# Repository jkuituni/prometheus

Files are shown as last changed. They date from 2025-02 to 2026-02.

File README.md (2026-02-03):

# Prometheus

Prometheus is a WDC 65816 based SingleBoardComputer aimed to be a fully usable self-containing computer platform.

System specification:

* CPU: WDC 65816 at 8MHz
* ROM: 8kB Firmware boot EPROM
* RAM: Up to 16MB of RAM via 4x 30pin SIMMs
* Video: Custom graphics chip "GRACE"
* Audio: Ensoniq EN5503 DOC
* I/O: 
  - RS232 serial port
  - Centronics port
  - 2x Atari "standard" joystick ports
  - ps/2 keyboard port
  - IDE massstorage interface
  - Standard floppydrive interface
* Other: 
  - DS1501 Realtime clock
  - 2x 16bit expansion slot connectors
  - 8bit expansion header

The graphics is implemented with a custom video controller called "[GRaCE](https://github.com/jkuituni/GRaCE)" using an additional FPGA board that connects via the two 40pin connectors. 

System controller is a CPLD that ties in the system, It generates the chip selects, various control signals and contains a DRAM controller.

More accurate specifications regarding the memory layout, graphics capabilities and generic system description will be 
added as they become available.

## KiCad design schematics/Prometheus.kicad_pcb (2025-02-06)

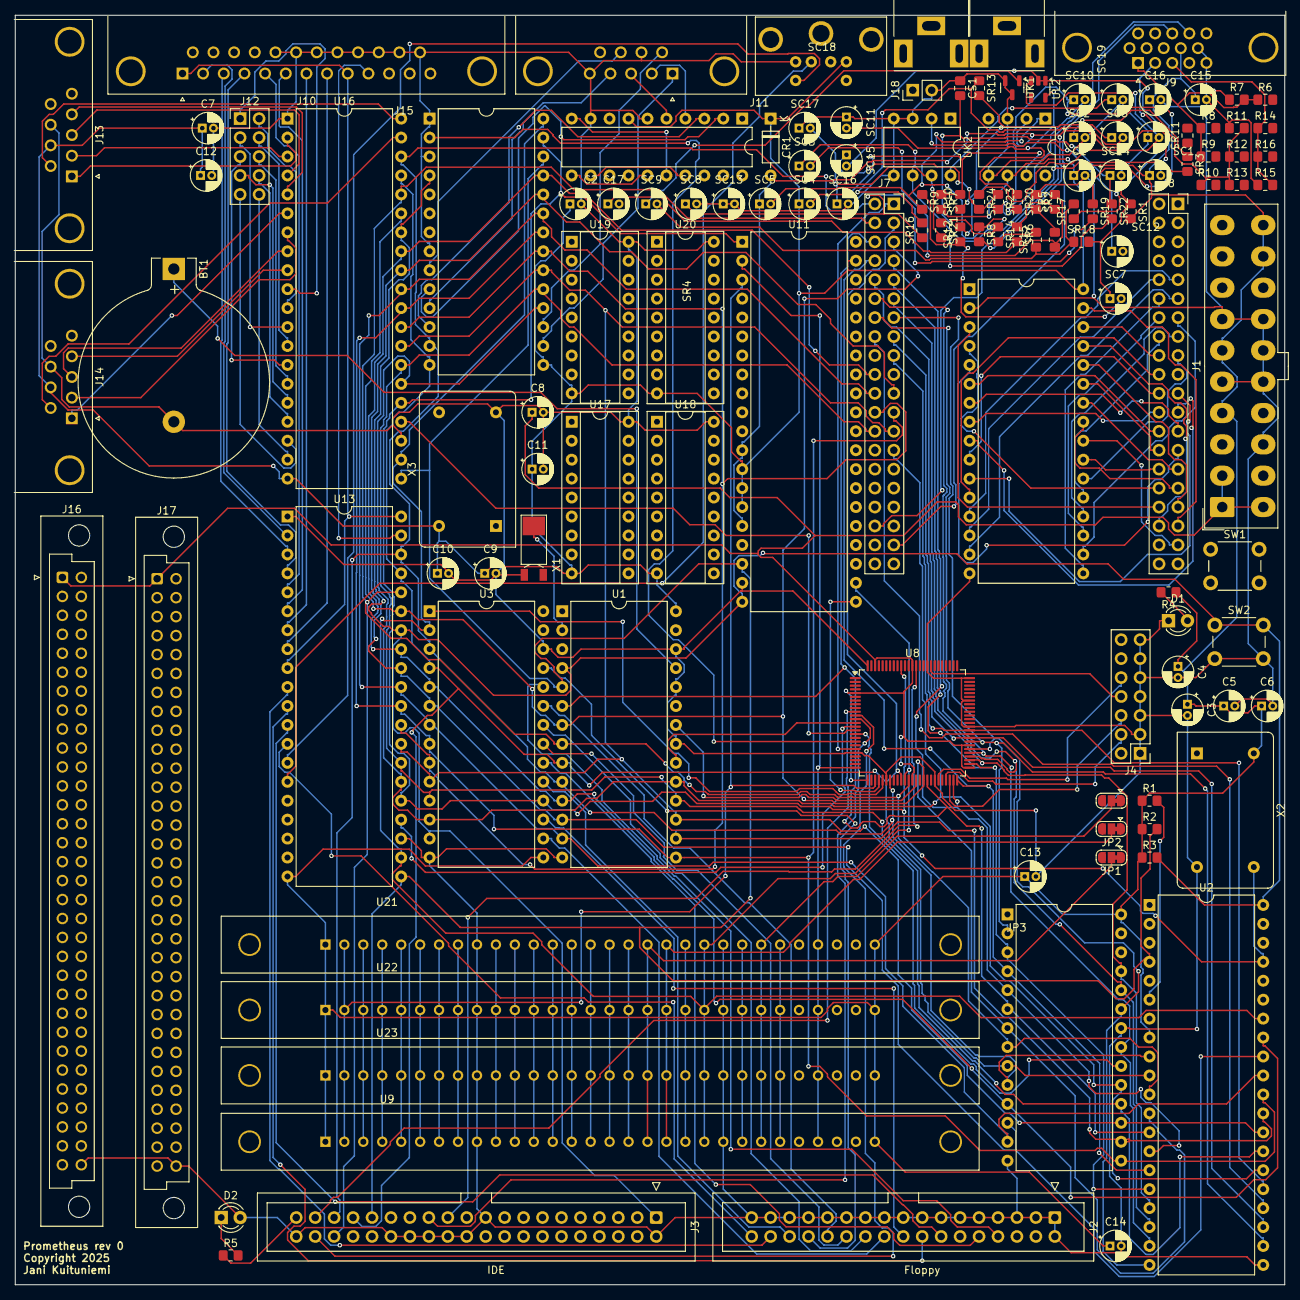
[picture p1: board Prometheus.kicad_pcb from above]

Board: 2 copper layers, 170.2 x 170.2 mm, 130 parts (0 on the bottom side), 191 nets.

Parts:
BT1: Battery; BatteryHolder_Keystone_104_1x23mm
C1, C2, C3, C4, C5, C6, C7, C8, C9, C10, C11: 0.1uF; CP_Radial_D4.0mm_P1.50mm
C12, C13, C14, C15, C16: C; CP_Radial_D4.0mm_P1.50mm
C17: 0.1u; CP_Radial_D4.0mm_P1.50mm
CR1: 1N914; D_DO-35_SOD27_P7.62mm_Horizontal
CS1: .1u; R_0805_2012Metric_Pad1.20x1.40mm_HandSolder
D1: Power LED; LED_D3.0mm
D2: IDE LED; LED_D3.0mm
J1: ATX Power Conn; Molex_Mini-Fit_Jr_5566-20A_2x10_P4.20mm_Vertical
J2: FDC Connector; IDC-Header_2x17_P2.54mm_Vertical
J3: IDE Connector; IDC-Header_2x20_P2.54mm_Vertical
J4: JTAG; PinHeader_2x07_P2.54mm_Vertical
J5: Left Audio; RCA
J6: Right Audio; RCA
J7: GRACE board interface 1; PinSocket_2x20_P2.54mm_Vertical
J8: GRACE board interface 2; PinSocket_2x20_P2.54mm_Vertical
J9: 15kHz Video Out; DSUB-15-HD_Female_Horizontal_P2.29x1.98mm_EdgePinOffset3.03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
J10: Centronics; DSUB-25_Female_Horizontal_P2.77x2.84mm_EdgePinOffset4.94mm_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
J11: ps/2 keyb; MINI-DIN-6-FULL-SHIELD
J12: Expansion; PinHeader_2x05_P2.54mm_Vertical
J13: Joy1; DSUB-9_Female_Horizontal_P2.77x2.84mm_EdgePinOffset4.94mm_H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
J14: Joy2; DSUB-9_Female_Horizontal_P2.77x2.84mm_EdgePinOffset4.94mm_H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
J15: rs232; DSUB-9_Male_Horizontal_P2.77x2.84mm_EdgePinOffset4.94mm_Hou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
J16, J17: DIN41612_02x32_AB; DIN41612_B_2x32_Female_Vertical_THT
J18: SPEAKER; PinHeader_1x02_P2.54mm_Vertical
JP1, JP2, JP3: Jumper_2_Open; SolderJumper-3_P1.3mm_Bridged12_RoundedPad1.0x1.5mm
R1, R2, R3, R5: R330; R_0805_2012Metric_Pad1.20x1.40mm_HandSolder
R4, R14: R470; R_0805_2012Metric_Pad1.20x1.40mm_HandSolder
R6, R10: R1100; R_0805_2012Metric_Pad1.20x1.40mm_HandSolder
R7, R11, R15: R150; R_0805_2012Metric_Pad1.20x1.40mm_HandSolder
R8, R12: R560; R_0805_2012Metric_Pad1.20x1.40mm_HandSolder
R9, R13: R270; R_0805_2012Metric_Pad1.20x1.40mm_HandSolder
R16: R240; R_0805_2012Metric_Pad1.20x1.40mm_HandSolder
SC1, SC4, SC5, SC6, SC7: 10p; CP_Radial_D4.0mm_P1.50mm
SC2, SC12, SC17: .1u; CP_Radial_D4.0mm_P1.50mm
SC3, SC9, SC16, SC19: 22u; CP_Radial_D4.0mm_P1.50mm
SC8: 1.5n; CP_Radial_D4.0mm_P1.50mm
SC10, SC15: 3.9n; CP_Radial_D4.0mm_P1.50mm
SC11: 220p; CP_Radial_D4.0mm_P1.50mm
SC13: 1.8n; CP_Radial_D4.0mm_P1.50mm
SC14: 470u/16v; CP_Radial_D4.0mm_P1.50mm
SC18: 560p; CP_Radial_D4.0mm_P1.50mm
SR1, SR4: 1K; R_0805_2012Metric_Pad1.20x1.40mm_HandSolder
SR2: 560; R_0805_2012Metric_Pad1.20x1.40mm_HandSolder
SR3: 2.7; R_0805_2012Metric_Pad1.20x1.40mm_HandSolder
SR5: 220; R_0805_2012Metric_Pad1.20x1.40mm_HandSolder
SR6: 100; R_0805_2012Metric_Pad1.20x1.40mm_HandSolder
SR7, SR8, SR9, SR10, SR12, SR13: 3.9K; R_0805_2012Metric_Pad1.20x1.40mm_HandSolder
SR11: 200K; R_0805_2012Metric_Pad1.20x1.40mm_HandSolder
SR14, SR15: 470K; R_0805_2012Metric_Pad1.20x1.40mm_HandSolder
SR16, SR19, SR20: 15K; R_0805_2012Metric_Pad1.20x1.40mm_HandSolder
SR17, SR18, SR23, SR24: 10K; R_0805_2012Metric_Pad1.20x1.40mm_HandSolder
SR21, SR22: 200; R_0805_2012Metric_Pad1.20x1.40mm_HandSolder
SW1: Power Switch; SW_PUSH_6mm
SW2: Reset Switch; SW_PUSH_6mm
U1: DS1501YN; DIP-28_W15.24mm
U2: wdc65c816; DIP-40_W15.24mm
U3: WD1772; DIP-28_W15.24mm
U8: XC9572XL-TQ100; TQFP-100_14x14mm_P0.5mm
U9, U21, U22, U23: SIMM16M; SIMM
U10: 2764; DIP-28_W15.24mm
U11: EN5503DOC; DIP-40_W15.24mm
U12: VRAM; DIP-32_W15.24mm
U13, U16: wdc65c22; DIP-40_W15.24mm
U14: wdc65c51; DIP-28_W15.24mm
U15: MAX233CPP; DIP-20_W7.62mm
U17, U18, U19, U20: 41464; DIP-18_W7.62mm_Socket
UK1: LM3340; SOT-23
UK2: LM380N-8; DIP-8_W7.62mm
UL1: MC34084; DIP-8_W7.62mm
UL2: TL072; SOT-23-5
X1: 32kHz; Crystal_SMD_FrontierElectronics_FM206
X2: 8MHz; Oscillator_DIP-14
X3: 1.8432MHz; Oscillator_DIP-14

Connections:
+12V: SC16.1, SC17.2, SR21.2, SR22.2, UK2.7 (VS)
/Audio/SND-SIG-: CR1.2 (A), SC1.2, SC5.1, SR8.2, U11.12 (VOLFDBK), U11.16 (SIG-), UL1.2 (-)
/Audio/SOUND.H: SR2.2, SR4.2
/RAM & ROM/DQ0: U9.3 (DQ0), U21.3 (DQ0), U22.3 (DQ0), U23.3 (DQ0)
/RAM & ROM/DQ1: U9.6 (DQ1), U21.6 (DQ1), U22.6 (DQ1), U23.6 (DQ1)
/RAM & ROM/DQ2: U9.10 (DQ2), U21.10 (DQ2), U22.10 (DQ2), U23.10 (DQ2)
/RAM & ROM/DQ3: U9.13 (DQ3), U21.13 (DQ3), U22.13 (DQ3), U23.13 (DQ3)
/RAM & ROM/DQ4: U9.16 (DQ4), U21.16 (DQ4), U22.16 (DQ4), U23.16 (DQ4)
/RAM & ROM/DQ5: U9.20 (DQ5), U21.20 (DQ5), U22.20 (DQ5), U23.20 (DQ5)
/RAM & ROM/DQ6: U9.23 (DQ6), U21.23 (DQ6), U22.23 (DQ6), U23.23 (DQ6)
/RAM & ROM/DQ7: U9.25 (DQ7), U21.25 (DQ7), U22.25 (DQ7), U23.25 (DQ7)
A0: J3.35, J7.2, U1.10 (A0), U2.9 (A0), U3.3 (A0), U8.32, U10.10 (A0), U13.38 (RS0), U14.13 (RS0), U16.38 (RS0)
A1: J3.33, J7.3, U1.9 (A1), U2.10 (A1), U3.4 (A1), U8.35, U10.9 (A1), U13.37 (RS1), U14.14 (RS1), U16.37 (RS1)
A2: J3.36, J7.4, U1.8 (A2), U2.11 (A2), U8.37, U10.8 (A2), U13.36 (RS2), U16.36 (RS2)
A3: J7.5, U1.7 (A3), U2.12 (A3), U8.41, U10.7 (A3), U13.35 (RS3), U16.35 (RS3)
A4: J7.6, U1.6 (A4), U2.13 (A4), U8.42, U10.6 (A4)
A5: J7.7, U2.14 (A5), U8.49, U10.5 (A5)
A6: J7.8, U2.15 (A6), U8.50, U10.4 (A6)
A7: J7.9, U2.16 (A7), U8.52, U10.3 (A7)
A8: J7.10, U2.17 (A8), U8.53, U10.25 (A8)
A9: J7.11, U2.18 (A9), U8.54, U10.24 (A9)
A10: J7.12, U2.19 (A10), U8.55, U10.21 (A10)
A11: J7.13, U2.20 (A11), U8.56, U10.23 (A11)
A12: J7.14, U2.22 (A12), U8.58, U10.2 (A12)
A13: J7.15, U2.23 (A13), U8.59
A14: J7.16, U2.24 (A14), U8.60
A15: J7.17, U2.25 (A15), U8.61
AUDIO_EN: U8.29, U11.21 (~CS)
CAS: U8.28, U9.2 (CAS), U11.3 (~CAS), U21.2 (CAS), U22.2 (CAS), U23.2 (CAS)
D0: J7.20, U1.11 (DQ0), U2.33 (D0), U3.5 (DAL0), U10.11 (D0), U13.33 (D0), U14.25 (D7), U16.33 (D0)
D1: J7.21, U1.12 (DQ1), U2.32 (D1), U3.6 (DAL1), U10.12 (D1), U13.32 (D1), U14.24 (D6), U16.32 (D1)
D2: J7.22, U1.13 (DQ2), U2.31 (D2), U3.7 (DAL2), U10.13 (D2), U13.31 (D2), U14.23 (D5), U16.31 (D2)
D3: J7.23, U1.15 (DQ3), U2.30 (D3), U3.8 (DAL3), U10.15 (D3), U13.30 (D3), U14.22 (D4), U16.30 (D3)
D4: J7.24, U1.16 (DQ4), U2.29 (D4), U3.9 (DAL4), U10.16 (D4), U13.29 (D4), U14.21 (D3), U16.29 (D4)
D5: J7.25, U1.17 (DQ5), U2.28 (D5), U3.10 (DAL7), U10.17 (D5), U13.28 (D5), U14.20 (D2), U16.28 (D5)
D6: J7.26, U1.18 (DQ6), U2.27 (D6), U3.11 (DAL6), U10.18 (D6), U13.27 (D6), U14.19 (D1), U16.27 (D6)
D7: J7.27, U1.19 (DQ7), U2.26 (D7), U3.12 (DAL7), U10.19 (D7), U13.26 (D7), U14.18 (D0), U16.26 (D7)
FDC_DRVA: J2.14, U13.12 (PB2)
FDC_DSKCHG: J2.34, U13.13 (PB3)
FDC_EN: U3.1 (~CS), U8.30
FDC_MTREN: J2.16, U13.11 (PB1)
FDC_SIDE: J2.32, U13.10 (PB0)
GND: BT1.2 (-), C1.2, C2.2, C3.2, C4.2, C5.2, C6.2, C7.2, C8.2, C9.2, C10.2, C11.2, C12.2, C13.2, C14.2, C15.2, C16.2, D1.1 (K), D2.2 (A), J1.5, J1.7, J1.13, J1.15, J1.16, J1.17, J2.1, J2.2, J2.3, J2.5, J2.7, J2.9, J2.11, J2.13, J2.15, J2.17, J2.19, J2.21, J2.23, J2.25, J2.27, J2.29, J2.31, J2.33, J3.2, J3.19, J3.22, J3.24, J3.26, J3.28, J3.30, J3.40, J4.1, J4.3, J4.5, J4.7, J4.9, J4.11, J4.13, J9.5, J9.10, J10.18, J10.19, J10.20, J10.21, J10.22, J10.23, J10.24, J10.25, J11.3, J13.8, J14.8, J15.5, J15.7, J16.b32, J17.b32, R7.1, R11.1, R15.1, SR2.1, SW2.2 (B), U1.14 (GND), U1.21 (GND), U1.24 (~KS), U1.26 (Vbaux), U2.21 (VSS), U3.14 (GND), U3.26 (~DDEN), U8.21 (GND), U8.31 (GND), U8.44 (GND), U8.62 (GND), U8.69 (GND), U8.75 (GND), U8.84 (GND), U8.100 (GND), U9.9 (GND), U9.22 (GND), U10.14 (GND), U10.22 (~OE), U11.19 (VSS), U12.2 (A16), U12.16 (GND), U13.1 (Vss), U13.23 (~CS2), U14.1 (VSS), U14.3 (~CS1), U14.8 (~RTS), U15.6 (GND), U15.9 (GND), U16.1 (Vss), U16.23 (~CS2), U17.18 (GND), U18.18 (GND), U19.18 (GND), U20.18 (GND), U21.9 (GND), U21.22 (GND), U22.9 (GND), U22.22 (GND), U23.9 (GND), U23.22 (GND), X1.2 (GND), X2.7 (GND), X3.7 (GND)
GNDA: CS1.1, J18.2, SC2.2, SC7.1, SC8.2, SC11.1, SC13.1, SC13.2, SC14.2, SC16.2, SC17.1, SC18.1, SC19.2, SR1.1, SR12.2, SR18.2, UK1.2, UK1.3, UK2.3 (-), UK2.4 (GND), UK2.5 (GND), UL1.3 (+), UL1.5 (+)
GNDPWR: C17.1, SR6.2
GRACE_EN: J7.1, U8.20
IDE_CS0: J3.37, U8.10
IDE_CS1: J3.38, U8.11
IOR: J3.25, U8.12
IOW: J3.23, U8.87
IRQ: J3.31, R2.2, U1.5 (~IRQ), U2.4 (~IRQ), U11.18 (~IRQ), U13.21 (~IRQ), U14.26 (~IRQ), U16.21 (~IRQ)
MA0: U9.4 (A0), U21.4 (A0), U22.4 (A0), U23.4 (A0)
MA1: U9.5 (A1), U21.5 (A1), U22.5 (A1), U23.5 (A1)
MA2: U9.7 (A2), U21.7 (A2), U22.7 (A2), U23.7 (A2)
MA3: U9.8 (A3), U21.8 (A3), U22.8 (A3), U23.8 (A3)
MA4: U9.11 (A4), U21.11 (A4), U22.11 (A4), U23.11 (A4)
MA5: U9.12 (A5), U21.12 (A5), U22.12 (A5), U23.12 (A5)
MA6: U9.14 (A6), U21.14 (A6), U22.14 (A6), U23.14 (A6)
MA7: U9.15 (A7), U21.15 (A7), U22.15 (A7), U23.15 (A7)
MA8: U9.17 (A8), U21.17 (A8), U22.17 (A8), U23.17 (A8)
MA9: JP1.1 (A), JP1.2 (B), U9.18 (A9), U21.18 (A9), U22.18 (A9), U23.18 (A9)
MA10: JP2.1 (A), JP2.2 (B), U9.19 (A10), U21.19 (A10), U22.19 (A10), U23.19 (A10)
MA11: JP3.1 (A), JP3.2 (B), U9.24 (A11), U21.24 (A11), U22.24 (A11), U23.24 (A11)
NMI: R1.2, U2.6 (~NMI)
unnamed: BT1.1 (+), U1.25 (Vbat)
unnamed: D1.2 (A), R4.2
unnamed: D2.1 (K), R5.2
unnamed: J2.8, U3.24 (~IP)
unnamed: J2.10, U3.20 (MO)
unnamed: J2.18, U3.17 (DIRC)
unnamed: J2.20, U3.16 (STEP)
unnamed: J2.22, U3.22 (WD)
unnamed: J2.24, U3.21 (WG)
unnamed: J2.26, U3.23 (~TR00)
unnamed: J2.28, U3.25 (~WPRT)
unnamed: J2.30, U3.19 (~RD)
unnamed: J3.39, R5.1
unnamed: J4.4, U8.47 (TMS)
unnamed: J4.6, U8.48 (TCK)
unnamed: J4.8, U8.83 (TDO)
unnamed: J4.10, U8.45 (TDI)
unnamed: J7.36, J9.14
unnamed: J7.37, J9.13
unnamed: J8.9, U12.13 (Q0)
unnamed: J8.10, U12.14 (Q1)
unnamed: J8.11, U12.15 (Q2)
unnamed: J8.12, U12.17 (Q3)
unnamed: J8.13, U12.18 (Q4)
unnamed: J8.14, U12.19 (Q5)
unnamed: J8.15, U12.20 (Q6)
unnamed: J8.16, U12.21 (Q7)
unnamed: J8.17, U12.22 (~CS1)
unnamed: J8.18, U12.30 (CS2)
unnamed: J8.20, U12.12 (A0)
unnamed: J8.21, U12.11 (A1)
unnamed: J8.22, U12.10 (A2)
unnamed: J8.23, U12.9 (A3)
unnamed: J8.24, U12.8 (A4)
unnamed: J8.25, U12.7 (A5)
unnamed: J8.26, U12.6 (A6)
unnamed: J8.27, U12.5 (A7)
unnamed: J8.28, U12.27 (A8)
unnamed: J8.29, U12.26 (A9)
unnamed: J8.30, U12.23 (A10)
unnamed: J8.31, U12.25 (A11)
unnamed: J8.32, U12.4 (A12)
unnamed: J8.33, U12.28 (A13)
unnamed: J8.34, U12.3 (A14)
unnamed: J8.35, U12.31 (A15)
unnamed: J8.36, U12.29 (~WE)
unnamed: J8.37, U12.24 (~OE)
unnamed: J9.1, R6.1, R7.2, R8.1, R9.1
unnamed: J9.2, R10.1, R11.2, R12.1, R13.1
unnamed: J9.3, R14.1, R15.2, R16.1
unnamed: J12.1, U16.10 (PB0)
unnamed: J12.2, U16.11 (PB1)
unnamed: J12.3, U16.12 (PB2)
unnamed: J12.4, U16.13 (PB3)
unnamed: J12.5, U16.14 (PB4)
unnamed: J12.6, U16.15 (PB5)
unnamed: J12.7, U16.16 (PB6)
unnamed: J12.8, U16.17 (PB7)
unnamed: J12.9, U16.18 (CB1)
unnamed: J12.10, U16.19 (CB2)
unnamed: SC3.2, SR4.1, SR5.2
unnamed: SR5.1, SR6.1
unnamed: SR14.2, SR15.2
unnamed: SC2.1, SR3.1
unnamed: SC3.1, SR3.2, UK2.6
unnamed: SC4.2, SR7.1, SR10.2, UL1.7
unnamed: SC5.2, SR8.1, SR9.2, UL1.1
unnamed: SC6.2, SR13.1, SR16.2
unnamed: SC8.1, SR16.1, SR19.2
unnamed: SC9.1, UK1.1
unnamed: SC9.2, SR15.1, SR17.2, SR18.1
unnamed: SC10.1, SR19.1, SR20.2
unnamed: SC15.1, SR23.1, SR24.2
unnamed: CS1.2, SC14.1, SR14.1, SR21.1, SR22.1
unnamed: J10.1, J10.9, U13.9 (PA7), U13.40 (CA1)
unnamed: J10.10, U13.39 (CA2)
unnamed: J10.2, U13.2 (PA0)
unnamed: J10.3, U13.3 (PA1)
unnamed: J10.4, U13.4 (PA2)
unnamed: J10.5, U13.5 (PA3)
unnamed: J10.6, U13.6 (PA4)
unnamed: J10.7, U13.7 (PA5)
unnamed: J10.8, U13.8 (PA6)
unnamed: J11.5, U13.14 (PB4)
unnamed: J11.1, U13.15 (PB5)
unnamed: U14.12 (RxD), U15.3 (R1OUT)
unnamed: U14.10 (TxD), U15.2 (T1IN)
unnamed: J15.8, U14.9 (~CTS)
unnamed: J15.1, U14.16 (~DCD)
unnamed: J15.6, U14.17 (~DSR)
unnamed: J15.4, U14.11 (~DTR)
unnamed: U15.11 (C2+(C2-)), U15.15 (C2+)
unnamed: U15.10 (V-(CS-)), U15.16 (C2-)
unnamed: J15.2, U15.4 (R1IN)
unnamed: J15.3, U15.5 (T1OUT)
unnamed: U15.12 (V-(C2+)), U15.17 (V-)
unnamed: J13.6, U16.40 (CA1)
unnamed: J14.6, U16.39 (CA2)
unnamed: J13.1, U16.2 (PA0)
unnamed: J13.2, U16.3 (PA1)
unnamed: J13.3, U16.4 (PA2)
unnamed: J13.4, U16.5 (PA3)
unnamed: J14.1, U16.6 (PA4)
unnamed: J14.2, U16.7 (PA5)
unnamed: J14.3, U16.8 (PA6)
unnamed: J14.4, U16.9 (PA7)
unnamed: SC12.1, UK2.2 (+)
unnamed: SC19.1, UK2.8 (BYPASS)
unnamed: SC7.2, SR9.1, SR12.1
unnamed: SC6.1, SR10.1, SR13.2
unnamed: SC18.2, SR24.1, UL2.3 (+)
unnamed: SC15.2, SR17.1, UL2.1, UL2.2 (-)
unnamed: SC11.2, SR20.1, UL2.5 (+)
unnamed: SC10.2, SR23.2
PHI2: U2.37 (PHI2), U3.18 (CLK), U8.91, U11.1 (CLK), U13.25 (PHI2), U14.27 (PHI2), U16.25 (PHI2), X2.8 (OUT)
RAS: U8.25, U9.27 (RAS), U11.2 (~RAS), U21.27 (RAS), U22.27 (RAS), U23.27 (RAS)
RES: J3.1, R3.2, SW2.1 (A), U1.4 (~RST), U2.40 (~RES), U3.13 (~MR), U11.20 (RES), U13.34 (~RES), U14.4 (~RES), U16.34 (~RES)
ROM_EN: U8.16, U10.20 (~CE)
RTC_CLK: U1.2 (X1), X1.3 (OUT)
RTC_EN: U1.20 (~CE), U8.13
RW: U2.34 (~RW), U3.2 (~RW), U8.36, U9.21 (WR), U11.22 (~WE), U13.22 (~RW), U14.28 (~RW), U16.22 (~RW), U21.21 (WR), U22.21 (WR), U23.21 (WR)
UART_EN: U8.18, U14.2 (CS0)
VIA1_EN: U8.14, U13.24 (CS1)
VIA2_EN: U8.15, U16.24 (CS1)
Vcc: C1.1, C2.1, C3.1, C4.1, C5.1, C6.1, C7.1, C9.1, C10.1, C11.1, C12.1, C13.1, C14.1, C15.1, C16.1, CR1.1 (K), J1.4, J1.6, J1.19, J1.20, J9.9, J11.4, J13.7, J14.7, R1.1, R2.1, R3.1, R4.1, SC1.1, SC4.1, SR1.2, SR7.2, U1.28 (Vcc), U2.8 (VDD), U3.15 (VCC), U9.1 (VCC), U9.30 (VCC), U10.28 (VCC), U11.13 (VOL-), U11.14 (WVREF), U11.15 (SIG+), U11.39 (VDD), U12.32 (VCC), U13.20 (VDD), U14.15 (VDD), U15.7 (VCC), U16.20 (VDD), U17.9 (VCC), U18.9 (VCC), U19.9 (VCC), U20.9 (VCC), U21.1 (VCC), U21.30 (VCC), U22.1 (VCC), U22.30 (VCC), U23.1 (VCC), U23.30 (VCC), UL1.6 (-), X2.14 (Vcc), X3.14 (Vcc)
Vcc33: C8.1, J1.1, J1.2, J1.11, J16.a1, J17.a1, U8.5 (VCC), U8.26 (VCCIO), U8.38 (VCCIO), U8.51 (VCCIO), U8.57 (VCC), U8.88 (VCCIO), U8.98 (VCC)
~OE: U1.22 (~OE), U8.39

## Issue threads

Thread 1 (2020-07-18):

Need an active high IRQ pin for FDC controller

ccureau, 2020-07-18:
All other IRQ signals are active low on the system. The floppy drive expects active high.

According to the datasheet, INTRQ is output only. Is it enough just to invert the signal to the existing IRQB line?

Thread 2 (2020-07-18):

PHI2 needs to be inverted on MARCy to generate BA signals

ccureau, 2020-07-18:
Bus Address appears on D[0..7] on the falling edge of PHI2. Refer to page 44 of the WDC 65c816 datasheet for a circuit diagram.

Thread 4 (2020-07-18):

RAM_EN pin on MARCy possibly not needed

ccureau, 2020-07-18:
According to the 30-pin SIMM datasheet, combinations of RAS and CAS select the SIMM for read or write. The only reason we would need a separate RAM_EN is if we want to work with memory that is not built onto the board, like an expansion.

ccureau, 2020-07-19:
After discussing with @jkuituni, it is agreed this pin is not necessary. Removed in commit 1d634c1

Closed 2020-07-19.

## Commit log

2020-06-27 Initial commit for Prometheus single board computer.
    [CPU_Power_Reset_Clock.sch, GRACE_&_VRAM.sch, IO_1.sch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]
2020-06-28 Remove old projects and associated stuff
    [CPU_Power_Reset_Clock.sch, GRACE_&_VRAM.sch, IO_1.sch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]
2020-06-28 Move No Connect on ATX pin 12 to actual pin
    [Prometheus.sch]
2020-06-28 Remove unneeded libaries from schematic library
    [Prometheus.sch]
2020-06-29 Cleanup and spot check for main sheet
    [Prometheus.sch]
2020-06-29 Added 8bit to 16bit IDE data handling latching.
    [RAM-ROM.sch, io-2.sch]
2020-06-29 draw boxes and fix power pins
2020-06-29 replace components in sheets
    [io-2.sch]
2020-06-30 Fixup heirarchial labels
    [MARCy.sch]
2020-06-30 add audio schematic, other fixes
    [MARCy.sch, Prometheus.sch, RAM-ROM.sch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]
2020-06-30 Removed EN5503DOC chip from IO2 sheet as it is now on it's own separate sheet. Changed description texts to reflect the change.
    [audio.sch, io-2.sch]
2020-06-30 Minor adjustment to io-2 sheet.
    [io-2.sch]
2020-07-02 Re-added 8->16bit IDE data handling via latches and buffers.
    [io-2.sch]
2020-07-09 Added missing IDE control signals for the latches, bus drivers, reads/writes and chip selects.
    [MARCy.sch, io-2.sch]
2020-07-09 Added missing FDC control signals.
    [MARCy.sch, io-2.sch]
2020-07-09 Fixes to FDC signal mapping.
    [MARCy.sch, io-1.sch]
2020-07-09 Fixes to chip references.
    [io-2.sch]
2020-07-09 Minor tweaks to labels and values.
    [Prometheus.sch, io-2.sch]
2020-07-09 Added support for Diskchange for FDC interface.
    [io-1.sch, io-2.sch]
2020-07-11 Add missing RAM MA-bus symbol.
    [RAM-ROM.sch]
2020-07-14 Replace global labels with herarchial labels
    [MARCy.sch]
2020-07-14 separate HDD from FDD, prepare to connect pins
    [io-2.sch]
2020-07-17 rework to include net labels, high IRQ line for FDC
    [io-2.sch]
2020-07-17 cosmetic work
    [io-2.sch]
2020-07-17 connect up I/O sheet 2
    [Prometheus.sch]
2020-07-17 Use the right component, idiot...
    [MARCy.sch]
2020-07-17 Opposite PHI2 and RWB trigger bank address on d0..7
    [MARCy.sch]
2020-07-17 Just so I don't forget...
    [MARCy.sch]
2020-07-18 another note for the future
    [io-2.sch]
2020-07-18 add bus labels, hierarchial labels
    [RAM-ROM.sch]
2020-07-18 begin wiring up the hierarchial sheets
    [MARCy.sch, Prometheus.sch, RAM-ROM.sch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]
2020-07-19 Issue #4: Remove RAM_EN pin
    [MARCy.sch, Prometheus.sch]
2020-07-19 Add SIMM size select jumpers
    [RAM-ROM.sch]
2020-07-19 rearrange schematic page
    [Prometheus.sch]
2020-07-19 clean up, added nc pins
    [grace-vram.sch]
2020-07-19 Finish connecting hierarchial pins
    [MARCy.sch, Prometheus.sch, grace-vram.sch]
2020-07-19 finish up hierarchial pins (as they stand now)
    [Prometheus.sch, audio.sch, io-1.sch]
2020-07-20 additional fixups
    [Prometheus.sch, grace-vram.sch, io-1.sch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]
2020-07-28 Added a few lost power connections and no_connect entries.
    [RAM-ROM.sch, io-1.sch]
2025-01-19 Added a whole bunch of footprints for symbols.
    [MARCy.kicad_sch, Prometheus.kicad_sch, RAM-ROM.kicad_sch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]
2025-01-19 Initial PCB layout and autoroute. Still lots missing.
    [Prometheus.kicad_pcb]
2025-02-04 Small tweaks here and there. Added a lot of missing footprint definitions.
    [MARCy.kicad_sch, Prometheus.kicad_sch, RAM-ROM.kicad_sch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]
2025-02-04 Initial PCB layout and route.
    [Prometheus.kicad_pcb]
2025-02-04 Added some missing footprints.
2025-02-04 Added analog audio section. Followed Apple IIGS schematics for this one as it uses the same EN5503DOC audio chip. Still a bit unclear how to connect the RCA jacks instead of the phonejack and analog 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
    [Prometheus.kicad_sch, audio.kicad_sch]
2025-02-05 Added a lot of missing footprints in the audio-section. Adjusted the PCB layout and re-routed the board.
    [Prometheus.kicad_pcb, audio.kicad_sch]
2025-02-06 Added the rest of the footprints for the analog audio and re-did the layout and routing of the PCB.
    [Prometheus.kicad_pcb, audio.kicad_sch]

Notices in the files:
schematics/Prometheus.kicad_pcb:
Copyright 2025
